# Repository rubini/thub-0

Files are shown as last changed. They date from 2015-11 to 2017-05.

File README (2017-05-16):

This is the "two hour uC board".  I designed it for a conference,
held on 2015-11 in Bozen.

The PCB can plug in a breadboard: the two power pins and the I/O strip
are there to that aim.

It as a atmega/attiny board (i.e. the arduino CPU).  You can fit
attiny48, atmega8, atmega88, atmega168 and atmega328.
If you mount the xtal you can program the fuses for 16MHz operation,
otherwise 8MHz.

Peripherals are:
   - 3 rgb leds
   - one button
   - one output led (on a pwm pin)
   - uext connector (uart, i2c, spi)
   - pin strip for analog
   - pin strip for other I/O pins

There is video of my talk, but I find myself quite boring. Moreover,
the screen is not visible in the video:
   https://www.sfscon.it/it/workshop/open-hardware-6/

After producing 50 and leaving 10 of them to conference attendees, I'm
now using the boards for other stuff, like teaching soldering (where
attendees can keep on device.

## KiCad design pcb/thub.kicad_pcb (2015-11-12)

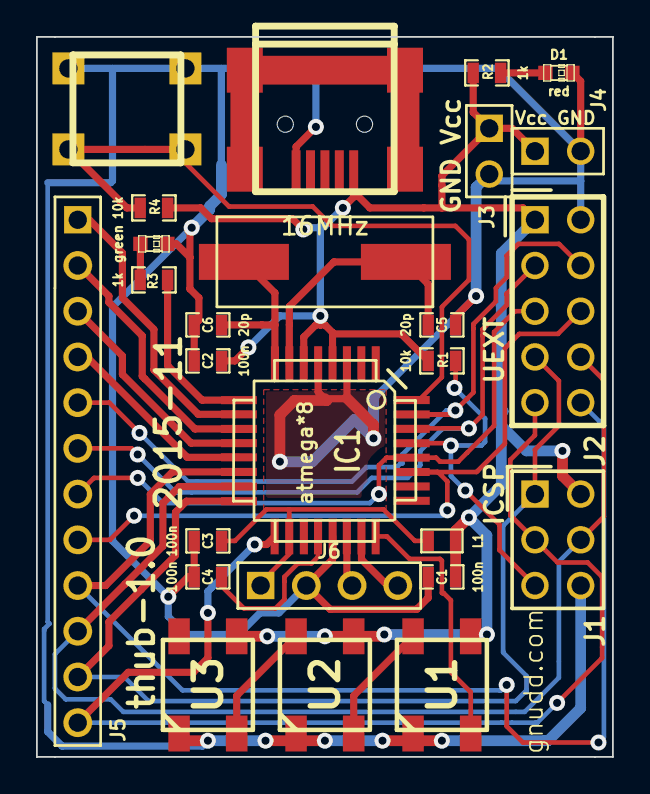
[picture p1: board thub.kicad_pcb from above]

Board: 2 copper layers, 32.0 x 40.0 mm, 26 parts (0 on the bottom side), 29 nets.

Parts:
C1, C2, C3, C4: 100n; SM0603_Capa
C5, C6: 20p; SM0603_Capa
CON1: USB-MINI-B; USB_MINI_B
D1: red; LED-0603
D2: green; LED-0603
IC1: atmega*8; TQFP32
J1: ICSP; pin_array_3x2
J2: UEXT; PIN_ARRAY_5x2
J3: millefori; PIN_ARRAY_2X1
J4: breadboard; PIN_ARRAY_2X1
J5: STRIP-12
J6: STRIP-4
L1: 10uH; SM0603
R1, R4: 10k; SM0603_Resistor
R2, R3: 1k; SM0603_Resistor
SW1: BUTTON; SW
U1, U2, U3: WS2812B
X1: 16MHz; Xtal-smd

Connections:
/ADC0: IC1.23, J6.4
/ADC7: IC1.22, J6.3
/AREF: C4.1, IC1.20
/BUTTON: IC1.32, R4.1, SW1.3, SW1.4
/LEDPWM: IC1.9, R3.1
/MISO: IC1.16, J1.1, J2.7, J5.11
/MOSI: IC1.15, J1.4, J2.8, J5.10
/Neopixel: IC1.24, U1.4
/PB0: IC1.12, J5.3
/PB1: IC1.13, J5.4
/PD6: IC1.10, J5.1
/PD7: IC1.11, J5.2
/RESET: IC1.29, J1.5, R1.2
/RXD: IC1.31, J2.4, J5.5
/SCK: IC1.17, J1.3, J2.9, J5.12
/SCL: IC1.28, J2.5, J5.7
/SDA: IC1.27, J2.6, J5.8
/SSEL: IC1.14, J2.10, J5.9
/TXD: IC1.30, J2.3, J5.6
/X1: C5.1, IC1.7, X1.1
/X2: C6.1, IC1.8, X1.2
GND: C1.2, C2.2, C3.2, C4.2, C5.2, C6.2, CON1.5, D1.2, D2.2, IC1.3, IC1.5, IC1.21, J1.6, J2.2, J3.2, J4.2, J6.2, SW1.1, SW1.2, U1.3, U2.3, U3.3
GNDPWR: CON1.6, CON1.7, CON1.8, CON1.9
unnamed: U1.2, U2.4
unnamed: U2.2, U3.4
unnamed: D2.1, R3.2
unnamed: D1.1, R2.2
VAA: C3.1, IC1.18, J6.1, L1.2
VCC: C1.1, C2.1, CON1.1, IC1.4, IC1.6, J1.2, J2.1, J3.1, J4.1, L1.1, R1.1, R2.1, R4.2, U1.1, U2.1, U3.1

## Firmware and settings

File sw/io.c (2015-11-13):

#include <thub.h>

static int uart_setup(void)
{
	/* This setup function should configure the uart pins and clock */

	/*
	 * Input clock is 16MHz, divided by 8 (using U2X) makes 2MHz.
	 * To get 2% precision we need 50 ticks per bit, so 40k bits,
	 * so let's try a 38400 rate:
	 *   2000000 / 38400 = 52.08
	 */
	regs[REG_UCSR0C] = 0;
	regs[REG_UBRR0L] = 51;

	/* size is 011 for 8-bit symbols */
	regs[REG_UCSR0C] = REG_UCSR0C_UCSZ1 | REG_UCSR0C_UCSZ0;
	regs[REG_UCSR0A] = REG_UCSR0A_UDRE | REG_UCSR0A_U2X;
	/* Enable interrupts on UART rx, and enable the device */
	regs[REG_UCSR0B] = REG_UCSR0B_RXCIE | REG_UCSR0B_TXEN | REG_UCSR0B_RXEN;
	return 0;
}

/* set up the timer: use 1024 as a prescaler, and overflow irq */
static int timer_setup(void)
{
	/* 16M / 256 / 256 = 244.14 Hz -- or 122.07 at 8MHz... */
	regs[REG_TCCR2B] = REG_TCCR2B_P256;
	regs[REG_TIMSK2] = REG_TIMSK2_TOIE2;

	asm("sei"); /* enable interrupts */
	return 0;
}

static void neopix_off_n(int n)
{
	int i;

	for (i = 0; i < n; i++)
		neopix_rgb(0, 0, 0);
	neopix_reset();
}

void setup(void)
{
	NEOPIX_SETDIR();
	neopix_reset();
	neopix_off_n(3);
	uart_setup();
	timer_setup();
}

void putc(int c)
{
	if (c == '\n')
		putc('\r');
	while ( !(regs[REG_UCSR0A] & REG_UCSR0A_UDRE) )
		;
	regs[REG_UDR0] = c;
}

int puts(const char *s)
{
	while (*s)
		putc (*s++);
	return 0;
}

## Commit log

2015-11-03 initial version, too many libs
    [thub.kicad_pcb, thub.sch]
2015-11-12 sw: copied Makefile from leder
2015-11-12 pcb: final minor details
    [thub.kicad_pcb]
2015-11-12 pcb/output: what I printed in 50 instances
    [thub-B_Cu.gbl, thub-B_Mask.gbs, thub-B_Paste.gbp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]
2015-11-13 sw/empty: toggle led
2015-11-13 sw: fix neopixel init
    [io.c]
